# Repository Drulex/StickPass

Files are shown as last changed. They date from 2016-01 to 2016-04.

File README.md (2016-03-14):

# STICKPASS

## What is the StickPass project?
StickPass is a hardware password manager based on the ATTINY85 microcontroller. It allows the user to securely store his identities (username/password combinations) on a physical device and use them with the press of a button. At the moment it uses the V-USB library to implement USB functionality in software.

## Scope
The scope of the project is to develop a low cost integrated hardware password management solution. The project is realized as a final year electrical engineering project and the timeline is 12 weeks at about 9 hours of work per week.

## Why ATTINY85?
There are two obvious ways of going when thinking about the architecture of this project:

1. Use an IC with integrated USB.
2. Use a general purpose IC and a separate chip acting as USB bridge.

Yet I chose to explore a third more obscure option: Use a software implementation of the USB protocol.

The reasons for this decision are the following:
* V-USB if fully compliant with USB1.1.
* ATTINY85 is an extremely small package (8 pin DIP package). There are no ICs with integrated USB that are this small.
* Very cheap (~1.67$) compared to other ICs with USB integrated or compared to using two ICs.
* Hardware is greatly simplified as the IC is powered directly from USB VCC and does not require a single external component (not even oscillator).
* This project does not require a lot of CPU and memory resources nor does it need full speed USB protocol.
* AVR chips are very well documented and used in various projects in the online community.
* Need to go from nothing to "production ready" in less than 150 hours.

## Compiling the firmware
At the moment this was only tested on Linux. Cross platform support is coming.

#### Linux
The following packages are required in order to build the firmware:
* avr-libc
* arvdude
* binutils-avr
* gcc-avr

If you are not using the USBTINY programmer to flash your ATTINY85 modify line 6 of the Makefile to call your programmer.

To compile the project: ``` make hex ```

To flash the chip: ``` make flash ```

To flash the fuses: ``` make fuse ```

#### OSX
Coming soon.

#### Windows
Coming soon... or not.

## Compiling the user application
In order to use the user application (StickApp) you will need a recent version of:
* gcc
* libusb

To compile the app: ``` make app ```

## Using the StickApp

#### Device initialization
```./stickapp --init <unlock key> ```

This will initialize the device with the given unlock key. This key must be used to unlock the device any time it is plugged in the future!
When used on an already initialized device it will wipe the memory contents and reset the key.

#### Send credentials to device
```./stickapp --send <idName> <idUsername> <idPassword> ```
* idName: nickname associated with credential
* idUsername: username associated with credential
* idPassword: password associated with credential

#### Clearing the EEPROM
``` ./stickapp --clear ```
Will clear the memory contents and preserve the unlock key.

#### Using credentials
To use the device:

1. Plug in computer. The LED should light up and stay solid. This means the device is locked.
2. Unlock the device using the unlock key.
3. A pushbutton shortpress (lesser than 1 second) will display and iterate through available idNames.
4. A pushbutton long press (greater than 1 second) will inject the idUsername, the TAB character and the idPassword.

## Limitations
Some decisions were made to implement some features (most of them related to memory management) with limitations in order to satisfy the requirements, but at the same time decrease complexity and ultimately save some time. I am obviously aware that these implementations are suboptimal and I plan on fixing them as soon as the semester is done and time allows.

##### Current limitations on version 1.0:
1. Maximum of 8 credentials capacity as per scheme below:
   * idName: 10 bytes
   * idUsername: 32 bytes
   * idPassword: 21 bytes
2. Unlock key size is 7 bytes.
3. No mechanisms implemented to prevent EEPROM corruption. This means that if you remove power during an EEPROM write cycle your data WILL be corrupted.

## Next version
I already have some ideas for the next iteration the main ones being:

1. External memory chip with hardware encryption.
2. NFC support for 2 factor authentication.
3. Rotating knob for navigation.
4. Tiny OLED matrix display.

If you have suggestions contact me at alexandru@jora.ca I would love to get some feedback.

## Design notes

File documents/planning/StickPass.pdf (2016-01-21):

F | S | S

3 Jan 16
M | T | W T | F | S | S

10 Jan 16
M | T | W T | F | S | S

17 Jan 16
M | T | W T | F | S | S

24 Jan 16
M | T | W T | F | S
1 | Documentation | 3.625 days?
2 | Rédaction du cahier des charges | 0.625 days?
3 | Rédaction du rapport d'étape | 0.5 days
4 | Rédaction du rapport technique final | 1 day?
5 | Préparation de la présentation orale | 1.5 days
6 | Conception du circuit électronique (prototype) | 2.875 days?
7 | Sélection du microcontrolleur | 1 day?
8 | Conception du circuit | 1.5 days
9 | Approvisionnement des composantes | 0.375 days?
10 | Test du circuit électronique (prototype) | 1 day?
11 | Assemblage du circuit | 0.25 days?
12 | Test de la programmation du microprogramme | 0.75 days?
13 | Sanity check du circuit | 0.5 days?
14 | Conception logiciel | 7 days
15 | Implémentation du pilote HID sur le microcontrolleur | 0.5 days
16 | Implémentation du protocole USB virtuel sur le microcontrolleur | 0.5 days
17 | Implémentation des requis fonctionnels du système | 3 days
18 | Implémentation des requis de sécurité du système | 1.5 days
19 | Implémentation de l'application usager | 1.5 days
20 | Test du logiciel | 4 days?
21 | Test des communications | 1.5 days?
22 | Test du protocol USB | 0.75 days?
23 | Test du pilote HID | 0.75 days?
24 | Test des requis fonctionnels | 1 day?
25 | Test des requis de sécurité | 0.5 days?
26 | Test de l'application usager | 0.75 days?
27 | Test de performance | 0.25 days?
28 | Fabriquation du prototype final | 3.625 days?
29 | Conception du PCB | 1 day?
30 | Révision du PCB | 0.25 days?
31 | Approvisionnement des composantes | 0.375 days?
32 | Fabrication du PCB | 0.5 days
33 | Assemblage PCB | 0.5 days?
34 | Test PCB | 1 day?
Name | Duration

StickPass - page1

M T W T | F | S | S

31 Jan 16
M | T | W T | F | S | S

7 Feb 16
M | T | W T | F | S | S

14 Feb 16
M | T | W T | F | S | S

21 Feb 16
M | T | W T | F | S

StickPass - page2

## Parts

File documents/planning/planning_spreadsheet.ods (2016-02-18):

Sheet: plan_task
Planification des tâches | Temps estimé (h) | Temp dépensé (h) | Temps restant (h)
Documentation | 21 | 7 | 14
Rédaction du rapport d'étape | 5 | 7 | 0
Rédaction du rapport technique final | 8 | 0 | 8
Préparation de la présentation orale | 8 | 0 | 8
Fabrication du circuit électronique (prototype) | 25 | 25 | 0
Sélection du microcontrolleur | 4 | 4 | 0
Conception du circuit | 6 | 6 | 0
Approvisionnement des composantes | 3 | 3 | 0
Assemblage du circuit | 2 | 2 | 0
Test de la programmation du microprogramme | 6 | 6 | 0
Sanity check du circuit | 4 | 4 | 0
Conception logiciel | 60 | 18 | 42
Implémentation du pilote HID sur le microcontrolleur | 4 | 4 | 0
Implémentation du protocole USB virtuel sur le microcontrolleur | 8 | 8 | 0
Implémentation des requis fonctionnels du système | 24 | 4 | 20
Implémentation des requis de sécurité du système | 12 | 0 | 12
Implémentation de l'application usager | 12 | 2 | 10
Test du logiciel | 44 | 10 | 34
Test des communications | 6 | 3 | 3
Test du protocol USB | 12 | 4 | 8
Test du pilote HID | 6 | 2 | 4
Test des requis fonctionnels | 8 | 1 | 7
Test des requis de sécurité | 4 | 0 | 4
Test de l'application usager | 6 | 0 | 6
Test de performance | 2 | 0 | 2
Fabriquation du prototype final | 29 | 12 | 17
Conception du PCB | 8 | 7 | 1
Révision du PCB | 2 | 2 | 0
Approvisionnement des composantes | 3 | 3 | 0
Fabrication du PCB | 4 | 0 | 4
Assemblage PCB | 4 | 0 | 4
Test PCB | 8 | 0 | 8
TOTAL | 179 | 72 | 107

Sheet: costs
Matériel | Coût estimé
Carte de développement | $10.00
Composantes électroniques | $60.00
Outils de débogage | $30.00
Services de fabrication PCB | $80.00
Total | $180.00

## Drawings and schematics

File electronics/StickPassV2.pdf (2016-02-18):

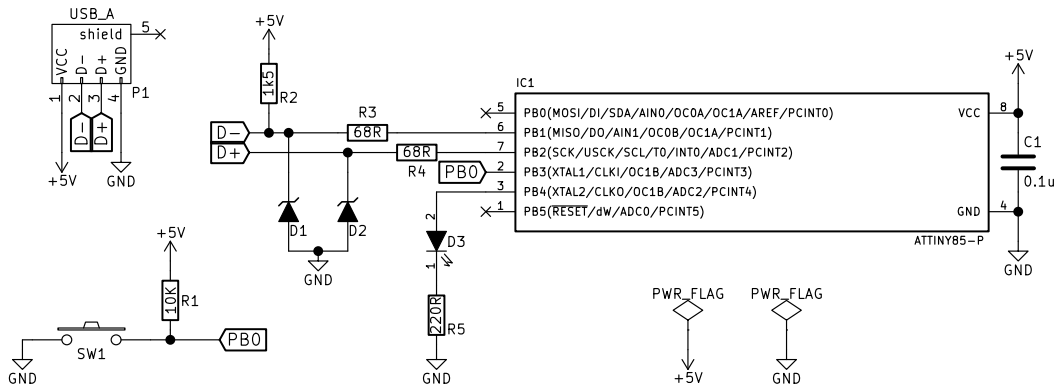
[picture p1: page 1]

File: StickPassV2.sch Sheet: / Alexandru Jora

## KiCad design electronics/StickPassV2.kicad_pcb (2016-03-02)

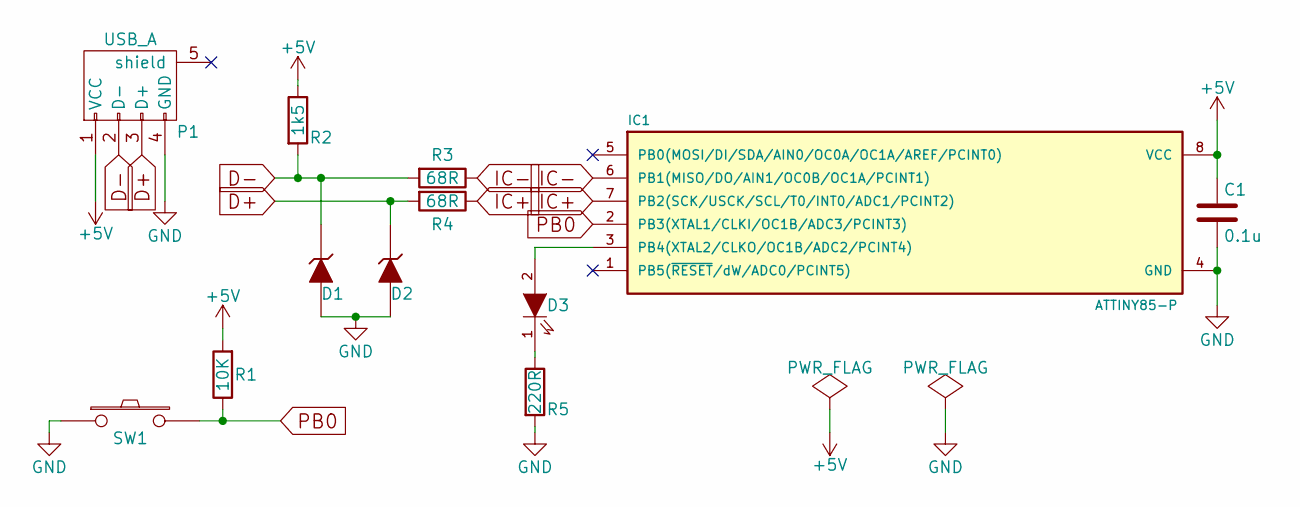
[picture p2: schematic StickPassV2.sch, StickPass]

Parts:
C1: 0.1u; Resistor_Horizontal_RM7mm
D1, D2: ZENER; Resistor_Horizontal_RM7mm
D3: LED; LED-5MM
IC1: ATTINY85-P; DIP-8_W7.62mm
P1: USB_A; usb_a_molex_48037-0001
R1: 10K; Resistor_Horizontal_RM10mm
R2: 1k5; Resistor_Horizontal_RM10mm
R3, R4: 68R; Resistor_Horizontal_RM7mm
R5: 220R; Resistor_Horizontal_RM10mm
SW1: SW_PUSH; SPST-4-PIN_6mm_thru

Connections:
+5V: C1.1, IC1.8 (VCC), P1.1 (VCC), R1.2, R2.1
D+: D2.1 (K), P1.3 (D+), R4.2
D-: D1.1 (K), P1.2 (D-), R2.2, R3.2
GND: C1.2, D1.2 (A), D2.2 (A), IC1.4 (GND), P1.4 (GND), R5.2, SW1.1
IC+: IC1.7 (PB2(SCK/USCK/SCL/T0/INT0/ADC1/PCINT2)), R4.1
IC-: IC1.6 (PB1(MISO/DO/AIN1/OC0B/OC1A/PCINT1)), R3.1
unnamed: D3.1 (K), R5.1
unnamed: D3.2 (A), IC1.3 (PB4(XTAL2/CLKO/OC1B/ADC2/PCINT4))
PB0: IC1.2 (PB3(XTAL1/CLKI/OC1B/ADC3/PCINT3)), R1.1, SW1.2

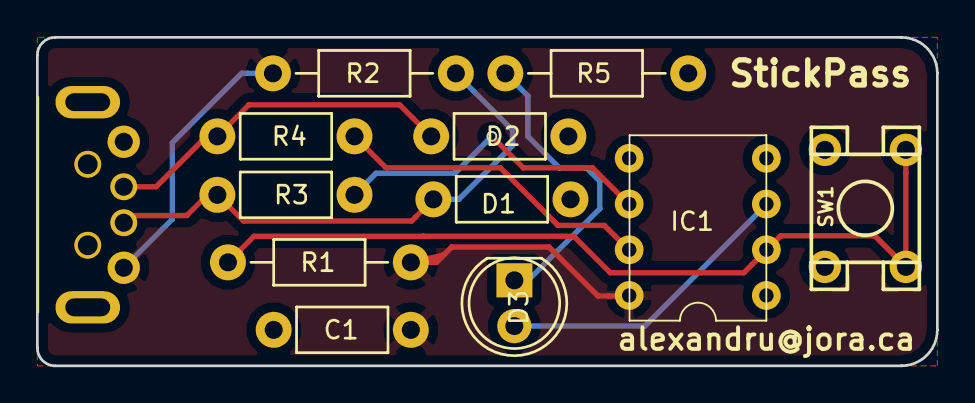
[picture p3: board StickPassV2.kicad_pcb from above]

Board: 2 copper layers, 50.0 x 18.2 mm, 12 parts (0 on the bottom side), 9 nets.

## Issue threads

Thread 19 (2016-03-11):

Erase memory after 5 failed attempts

Drulex, 2016-03-11:
Erase EEPROM after 5 failed attempts to unlock the device.

Drulex, 2016-04-03:
Done

Closed 2016-04-03.

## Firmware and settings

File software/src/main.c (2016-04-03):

/*
 * File: main.c
 * Project: StickPass
 * Author: Alexandru Jora (alexandru@jora.ca)
 * Creation Date: 2016-01-27
 * License: GNU GPL v3 (see LICENSE)
 *
 */

#include "main.h"

/*
 * This is called when the host send a usb_msg on control enpoint 0
 * It parses requests made by the host which can be HID related (required by spec)
 * or requests defined by us.
 */
usbMsgLen_t usbFunctionSetup(unsigned char data[8]) {
    usbRequest_t *rq = (void *)data;

    if((rq->bmRequestType & USBRQ_TYPE_MASK) == USBRQ_TYPE_CLASS) {
        switch(rq->bRequest) {

            //send NO_KEYS_PRESSED
            case USBRQ_HID_GET_REPORT:
                usbMsgPtr = (void *)&keyboard_report;
                keyboard_report.modifier = 0;
                keyboard_report.keycode = 0;
                return sizeof(keyboard_report);

            case USBRQ_HID_SET_REPORT:
                return (rq->wLength.word == 1) ? USB_NO_MSG : 0;

            // send idleRate to PC as per spec
            case USBRQ_HID_GET_IDLE:
                usbMsgPtr = &idleRate;
                return 1;

            // set idleRate as per spec
            case USBRQ_HID_SET_IDLE:
                idleRate = rq->wValue.bytes[1];
                return 0;
        }
    }
    // other requests
    else {
        switch(rq->bRequest) {
            case USB_INIT_DEVICE:
                clearEEPROM(1);
                idCnt = 0;
                return USB_NO_MSG;

            case USB_UNLOCK_DEVICE:
                // check if 5 failed unlock attempts occured
                if(unlockAttempts == 5) {
                    clearEEPROM(1);
                    unlockAttempts = 0;
                    return 0;
                }
                else
                    return USB_NO_MSG;

            case USB_ID_UPLOAD:
                if(flagUnlocked)
                    return USB_NO_MSG;
                else
                    return 0;

            case USB_CLEAR_EEPROM:
                if(flagUnlocked) {
                    clearEEPROM(0);
                    idCnt = 0;
                }
                return 0;
        }
    }
    return 0;
}

/*
 * This function is called when usbFunctionSetup return USB_NO_MSG
 * We can only receive chunks of 8 bytes so the state value
 * is stored in the first byte of the data buffer
 *
 */
usbMsgLen_t usbFunctionWrite(uint8_t * data, unsigned char len) {
    unsigned char i;
    idState = data[0];
    switch(idState) {
        case STATE_INIT_DEVICE:
            // memory has been wiped now we write master key to it
            setMasterKey((char *)&data[1]);
            flagUnlocked = 1;
            LED_LOW();
            return 1;

        case STATE_UNLOCK_DEVICE:
            getMasterKey(&masterKey[0]);
            // check if keys match
            if(memcmp(masterKey, &data[1], 7) == 0) {
                flagUnlocked = 1;
                LED_LOW();
                unlockAttempts = 0;
            }
            else
                unlockAttempts++;
            return 1;

        case STATE_ID_UPLOAD_INIT:
            // clear credentials structure and reset msg pointer
            clearCred(&credReceived);
            idMsgPtr = 0;
            return 1;

        case STATE_ID_NAME_SEND:
            for(i = 1; i < len; i++) {
                credReceived.idName[idMsgPtr] = data[i];
                idMsgPtr++;
            }
            return 1;

        case STATE_ID_NAME_DONE:
            idMsgPtr = 0;
            return 1;

        case STATE_ID_USERNAME_SEND:
            for(i = 1; i < len; i++) {
                credReceived.idUsername[idMsgPtr] = data[i];
                idMsgPtr++;
            }
            return 1;

        case STATE_ID_USERNAME_DONE:
            idMsgPtr = 0;
            return 1;

        case STATE_ID_PASS_SEND:
            for(i = 1; i < len; i++) {
                credReceived.idPassword[idMsgPtr] = data[i];
                idMsgPtr++;
            }
            return 1;

        case STATE_ID_PASS_DONE:
            flagCredReady = 1;
            update_credential(credReceived);
            return 1;
    }

    return 1;
}

int main() {
    // variables declaration
    unsigned char i;
    cred_t cred;

    // Modules initialization
    LED_Init();
    timer1_Init();
    PB_INIT();
    LED_HIGH();

    // variables init
    clearKeyboardReport();
    clearCred(&cred);

    // global interrupts off
    cli();

    // get number of credentials in EEPROM
    getCredCount();
    idCnt = credCount;

    // initialize usb library
    usbInit();

    // enforce re-enumeration
    usbDeviceDisconnect();
    for(i = 0; i<250; i++) {
        wdt_reset();
        _delay_ms(2);
    }

    usbDeviceConnect();

    LED_LOW();
    _delay_ms(500);
    LED_HIGH();

    // Enable 1s watchdog
    wdt_enable(WDTO_1S);

    // Enable global interrupts after re-enumeration
    sei();

    while(1) {
        wdt_reset();
        usbPoll();

        // only if device is unlocked
        if(flagUnlocked == 1) {
            // PB press detection
            if(!(PINB & (1<<PB3))) {
                // debouncing
                if(state == STATE_WAIT && pbCounter == 255) {
                    // short PB press
                    state = STATE_INIT;
                    flagDone = 0;// reset counter

                    // iterate to next idCnt
                    if(idCnt < credCount) {
                        idCnt++;
                    }
                    else
                        idCnt = 1;

                    counter100ms = 0;

                    while(!(PINB & (1<<PB3)) && !pbHold) {
                        // waiting for PB long press event
                        wdt_reset();
                        // if PB is held for 1.0s
                        if(counter100ms >= 10) {
                            counter100ms = 0;
                            state = STATE_LONG_KEY;
                            // send idUsername
                            pbHold = 1;
                            flagDone = 0;
                        }
                    }
                }
                pbHold = 0;
                pbCounter = 0;
            }
            // debouncing
            if(pbCounter < 255)
                pbCounter++;

            if(usbInterruptIsReady() && state != STATE_WAIT && !flagDone) {
                unsigned char sendKey;
                switch(state) {
                    case STATE_INIT:
                        clearCred(&cred);
                        getCredentialData(idCnt, &cred);
                        credPtr = 0;
                        state = STATE_SEND_ID_NAME;
                        flagKeyCleared = 0;

                    case STATE_SEND_ID_NAME:
                        sendKey = cred.idName[credPtr];
                        if(flagKeyCleared) {
                            buildReport(sendKey);
                        }

                        else {
                                if(clearKeyCnt == 10) {
                                clearKeyCnt = 0;
                                flagKeyCleared = 1;
                                buildReport(sendKey);
                            }

                            else {
                                buildReport(KEY_BS);
                                clearKeyCnt++;
                            }
                        }
                        state = STATE_RELEASE_ID_NAME;
                        break;

                    case STATE_RELEASE_ID_NAME:
                        // always send empty report when done sending a key
                        buildReport(0);

                        // upgrade credPtr only if we are not sending backspace key
                        if(flagKeyCleared)
                            credPtr++;

                        // if the next char is NULL
                        if(cred.idName[credPtr] == '\0') {
                            flagDone = 1;
                            credPtr = 0;
                            flagKeyCleared = 0;
                            state = STATE_WAIT;
                        }
                        // the next char is valid so we go back to state_short_key
                        else {
                            state = STATE_SEND_ID_NAME;
                        }
                        break;

                    case STATE_LONG_KEY:
                        credPtr = 0;
                        flagKeyCleared = 0;
                        state = STATE_SEND_ID_USERNAME;

                    case STATE_SEND_ID_USERNAME:
                        sendKey = cred.idUsername[credPtr];
                        // clear the previous idName
                        if(flagKeyCleared)
                            buildReport(sendKey);
                        else {
                            if(clearKeyCnt == 10) {
                                clearKeyCnt = 0;
                                flagKeyCleared = 1;
                                buildReport(sendKey);
                            }

                            else {
                                buildReport(KEY_BS);
                                clearKeyCnt++;
                            }
                        }

                        state = STATE_RELEASE_ID_USERNAME;
                        break;

                    case STATE_RELEASE_ID_USERNAME:
                        // always send empty report when done sending a key
                        buildReport(0);
                        if(flagKeyCleared)
                            credPtr++;

                        // if the next char is NULL
                        if(cred.idUsername[credPtr] == '\0') {
                            state = STATE_SEND_TAB;
                        }
                        // the next char is valid so we go back to state_short_key
                        else {
                            state = STATE_SEND_ID_USERNAME;
                        }
                        break;

                    case STATE_SEND_TAB:
                        // send tab character
                        buildReport(KEY_TAB);
                        state = STATE_RELEASE_TAB;
                        break;

                    case STATE_RELEASE_TAB:
                        buildReport(0);
                        credPtr = 0;
                        state = STATE_SEND_ID_PASSWORD;
                        break;

                    case STATE_SEND_ID_PASSWORD:
                        sendKey = cred.idPassword[credPtr];
                        buildReport(sendKey);
                        state = STATE_RELEASE_ID_PASSWORD;
                        break;

                    case STATE_RELEASE_ID_PASSWORD:
                        // always send empty report when done sending a key
                        buildReport(0);
                        credPtr++;

                        // we are done injecting data
                        if(cred.idPassword[credPtr] == '\0') {
                            flagDone = 1;
                            state = STATE_WAIT;
                        }
                        // the next char is valid so we go back to state_short_key
                        else {
                            state = STATE_SEND_ID_PASSWORD;
                        }
                        break;

                    // should not happen
                    default:
                        state = STATE_WAIT;
                }

                usbSetInterrupt((void *)&keyboard_report, sizeof(keyboard_report));
                LED_TOGGLE();
            }
        }
    }
    return 0;
}

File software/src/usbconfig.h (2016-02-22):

/* Name: usbconfig.h
 * Project: V-USB, virtual USB port for Atmel's(r) AVR(r) microcontrollers
 * Author: Christian Starkjohann
 * Creation Date: 2005-04-01
 * Tabsize: 4
 * Copyright: (c) 2005 by OBJECTIVE DEVELOPMENT Software GmbH
 * License: GNU GPL v2 (see License.txt), GNU GPL v3 or proprietary (CommercialLicense.txt)
 */

#ifndef __usbconfig_h_included__
#define __usbconfig_h_included__

/*
General Description:
This file is an example configuration (with inline documentation) for the USB
driver. It configures V-USB for USB D+ connected to Port D bit 2 (which is
also hardware interrupt 0 on many devices) and USB D- to Port D bit 4. You may
wire the lines to any other port, as long as D+ is also wired to INT0 (or any
other hardware interrupt, as long as it is the highest level interrupt, see
section at the end of this file).
+ To create your own usbconfig.h file, copy this file to your project's
+ firmware source directory) and rename it to "usbconfig.h".
+ Then edit it accordingly.
*/

/* ---------------------------- Hardware Config ---------------------------- */

#define USB_CFG_IOPORTNAME      B
/* This is the port where the USB bus is connected. When you configure it to
 * "B", the registers PORTB, PINB and DDRB will be used.
 */
#define USB_CFG_DMINUS_BIT      1
/* This is the bit number in USB_CFG_IOPORT where the USB D- line is connected.
 * This may be any bit in the port.
 */
#define USB_CFG_DPLUS_BIT       2
/* This is the bit number in USB_CFG_IOPORT where the USB D+ line is connected.
 * This may be any bit in the port. Please note that D+ must also be connected
 * to interrupt pin INT0! [You can also use other interrupts, see section
 * "Optional MCU Description" below, or you can connect D- to the interrupt, as
 * it is required if you use the USB_COUNT_SOF feature. If you use D- for the
 * interrupt, the USB interrupt will also be triggered at Start-Of-Frame
 * markers every millisecond.]
 */
#define USB_CFG_CLOCK_KHZ       (F_CPU/1000)
/* Clock rate of the AVR in kHz. Legal values are 12000, 12800, 15000, 16000,
 * 16500, 18000 and 20000. The 12.8 MHz and 16.5 MHz versions of the code
 * require no crystal, they tolerate +/- 1% deviation from the nominal
 * frequency. All other rates require a precision of 2000 ppm and thus a
 * crystal!
 * Since F_CPU should be defined to your actual clock rate anyway, you should
 * not need to modify this setting.
 */
#define USB_CFG_CHECK_CRC       0
/* Define this to 1 if you want that the driver checks integrity of incoming
 * data packets (CRC checks). CRC checks cost quite a bit of code size and are
 * currently only available for 18 MHz crystal clock. You must choose
 * USB_CFG_CLOCK_KHZ = 18000 if you enable this option.
 */

/* ----------------------- Optional Hardware Config ------------------------ */

/* #define USB_CFG_PULLUP_IOPORTNAME   D */
/* If you connect the 1.5k pullup resistor from D- to a port pin instead of
 * V+, you can connect and disconnect the device from firmware by calling
 * the macros usbDeviceConnect() and usbDeviceDisconnect() (see usbdrv.h).
 * This constant defines the port on which the pullup resistor is connected.
 */
/* #define USB_CFG_PULLUP_BIT          4 */
/* This constant defines the bit number in USB_CFG_PULLUP_IOPORT (defined
 * above) where the 1.5k pullup resistor is connected. See description
 * above for details.
 */

/* --------------------------- Functional Range ---------------------------- */
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

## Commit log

2016-01-21 Updated documentation
    [planning_spreadsheet.ods]
2016-01-27 Modified Makefile as per sample found online.
2016-01-28 Add Kicad electronic project files.
    [StickPassV2.kicad_pcb, StickPassV2.sch]
2016-01-28 Modify the prototype usbconfig.h file to correspond to circuit.
2016-01-28 Fix weird type in usbconfig.h.
    [usbconfig.h]
2016-01-29 Add some test code to flash LED via USB.
2016-01-29 Add oscillator calibration routine (created by cpldcpu).
2016-01-29 Modify Makefile to add ability to flash fuses.
2016-02-04 Configuring V-USB to use interrupt endpoint 1.
2016-02-04 Restructure main.c to test interrupt in data transfer to host.
2016-02-04 Add interrupt in functionality to user app.
2016-02-04 User app: display VID and PID in hex.
2016-02-04 Move led library to its own header file.
2016-02-08 Debounce on switch press.
2016-02-13 Modify usbconfig.h in order to use device as HID.
2016-02-13 Modify usbFunctionWrite to control the LED.
2016-02-18 Update planning spreadsheet.
    [planning_spreadsheet.ods]
2016-02-18 Update electronic circuit files.
    [StickPassV2.sch]
2016-02-22 Fix bug in PB init!
    [led.h]
2016-02-22 Setup timer1 to 100ms.
2016-02-22 Add timer1 routines in its own module.
2016-02-22 Modify Makefile to create timer1 object file.
2016-02-22 Add support to turn LED ON or OFF from usbFunctionSetup.
2016-02-22 Switch back to the other VID/PID pair that supports control OUT requests.
2016-02-25 Implementing state machine to send ID_BLOCKS to device.
2016-02-27 Fix credentials module to not use global cred_t.
    [main.c]
2016-02-27 Fix terrible bug in long PB detection. I don't even understand how it could have worked in the previous version of the code...
    [main.c]
2016-02-28 Adjust credentials module to resize idPassword to 21 bytes and free 8 bytes to use for calibration data in EEPROM.
2016-02-29 Implementing device protection via key.
2016-03-02 Update electronic schematic and add gerber files.
    [StickPassV2-B.Cu.gbl, StickPassV2-B.Mask.gbs, StickPassV2-B.SilkS.gbo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]
2016-03-02 Implement init device functionality.
2016-03-11 At EEPROM erase after 5 failed attempts at unlocking device.
    [main.c]
